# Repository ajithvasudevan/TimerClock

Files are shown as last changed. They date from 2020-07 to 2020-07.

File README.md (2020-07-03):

# TimerClock
An Arduino + RTC (and optionally Wemos) - based Clock and Timer with Alarm

# About
This project implements a Digital Alarm-Clock and Timer (time counter, also with alarm). 

# Button Operations
This Clock-Timer has 3 buttons - MODE, SET and RESET. All functions and settings are done using these buttons. This is described below.

## Displaying TIMER and CLOCK
When the ClockTimer is powered ON, it displays the CLOCK.
While CLOCK is displayed, long-pressing (LP) MODE button changes the display to TIMER, which displays counting time in minutes and seconds.
While TIMER is displayed, long-pressing (LP) MODE button changes the display to CLOCK, which displays the current time in 12-hr format.

## Timer and Resetting Timer to 00:00
The Timer counts time in seconds and minutes starting from 0 seconds, up to 99 minutes and 59 seconds, after which it starts counting from 0 seconds again.
During the time counting, the Timer alarm rings once when the displayed Time (mm:ss) matches the Timer Alarm setting.
While the Timer (or Clock) is displayed, the Timer count can be reset to 00:00 by short-pressing (SP) the RESET button. This causes the Timer to re-start counting from 0 seconds.

## Timer-Alarm Setting
While TIMER is displayed, MODE SP (Short Press) to change display to Timer-Alarm (Minutes and Seconds) with blinking Timer-Alarm Seconds. Now SET SP increments Timer-Alarm Seconds and SET LP decrements Timer Alarm Seconds.
MODE SP again blinks the Timer-Alarm Minutes display. Now SET SP increments Timer-Alarm Minutes and SET LP decrements Timer-Alarm Minutes.
MODE SP again returns the display to TIMER.

## Setting Timer Alarm to 00:00 quickly
The Timer-Alarm display can be set to 00:00 quickly by MODE LP during the blinking phase of Timer-Alarm Setting. This disables the Timer Alarm Ringing.

## Clock Setting
While CLOCK is displayed, MODE can be single-pressed (SP) to blink the Minutes display. Now SET SP increments Minutes and SET LP decrements Minutes.
MODE SP again blinks the Hours display. Now SET SP increments Hours and SET LP decrements Hours.
MODE SP again returns the display to CLOCK, with the changed time.

## Clock Alarm Setting
While CLOCK is displayed, SET LP to display the CLOCK ALARM TIME. Now MODE SP to blink the Clock Alarm Minutes display. Now SET SP increments Clock Alarm Minutes and SET LP decrements Clock Alarm Minutes.
MODE SP again blinks the Clock Alarm Hours display. Now SET SP increments Clock Alarm Hours and SET LP decrements Hours.
MODE MODE SP again returns the display to CLOCK ALARM TIME, with the changed Clock Alarm time.
MODE LP to exit Clock Alarm Setting and go back to Clock display.

# Schematic from KiCAD
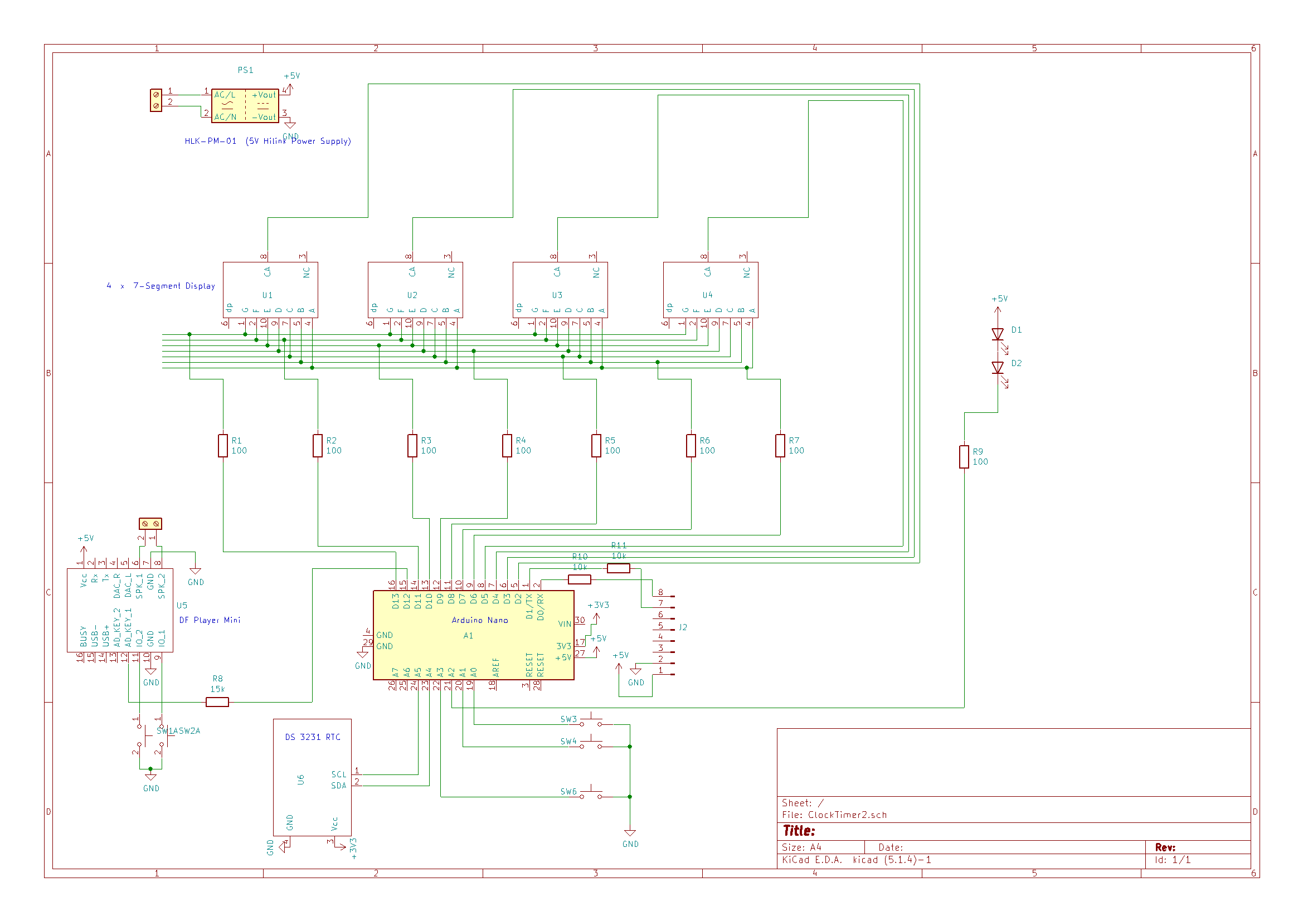
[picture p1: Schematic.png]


# PCM Image from KiCAD
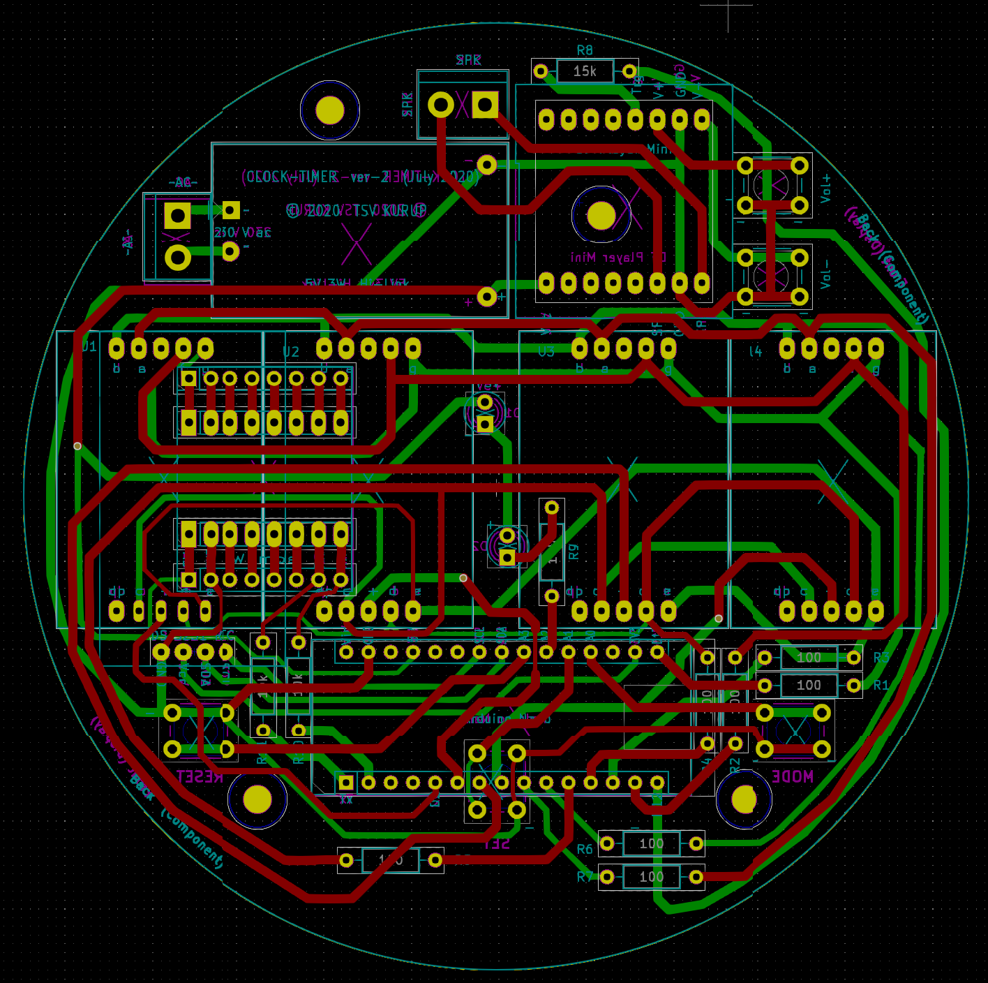
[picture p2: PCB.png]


# Notes

* A **DS3231 RTC** is used to keep accurate time. 
* The **DS 3231** may be removed and a **Wemos D1 Mini** with appropriate code may be used to push *Network Time* to the Arduino. This requires code changes to the Arduino as well. 
* The Wemos-Arduino interfacing is via Serial Rx-Tx lines.
* A6 and A7 of Arduino cannot be used as Digital IO pins. They can be used as Analog inputs only. So these are not suitable for use as button pins with libraries like AceButton.
* A DF Player Mini is used to make the alarm sound.
* Arduino's pin D13, being a communication pin as well, has digital noise on it during boot. Hence this is not suitable as a trigger pin for the DF Player Mini. Specifically, the DF Player starts playing continuously on boot if D13 is used.
* If the DF Player is triggered using Arduino pin D12 directly, there is a 'bep-bep-bep' kind of noise in the played back sound. This went away when a 15k resistor was used in this trigger line.

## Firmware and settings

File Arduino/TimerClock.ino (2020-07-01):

#include <Wire.h>
#include <EEPROM.h>
#include <AceButton.h>
#include "RTClib.h"
RTC_DS3231 rtc;
using namespace ace_button;

int modePin = A0;
int resetPin = A1;
int colonPin = A2;
int setPin = A3;
int alarmOut = 12;
int SET_BUTTON_STATE = 0;
int DISPLAY_MODE = 0;
int TIMER_MODE = 0;
int hr, mt;
int SET_DELAY = 50;
int timeChanged = 0;
int baseDelay = 1000;
int bias = 300;
int setDelayCtr = 0;

int CLOCK_SEC_PREV = 0;
int CLOCK_SEC = 0;
int CLOCK_MIN = 0;
int CLOCK_HR = 0;
int CLOCK_SEC_AL = 0;
int CLOCK_SEC_AL_ADDR = 0;

int CLOCK_MIN_AL_ADDR = 1;
int CLOCK_MIN_AL = EEPROM.read(CLOCK_MIN_AL_ADDR);

int CLOCK_HR_AL_ADDR = 2;
int CLOCK_HR_AL = EEPROM.read(CLOCK_HR_AL_ADDR);

int TIME_MIN = 0;
int TIME_SEC = 0;

int TIME_MIN_AL_ADDR = 3;
int TIME_MIN_AL = EEPROM.read(TIME_MIN_AL_ADDR);

int TIME_SEC_AL_ADDR = 4;
int TIME_SEC_AL = EEPROM.read(TIME_SEC_AL_ADDR);

int disp_left = 0;
int disp_right = 0;

int prev_second = 0;
int msec = 0;
long millisAtZero = 0;
bool zeroPad = true;
int colonState = 0;

AceButton mode_button(modePin, HIGH, 0);
AceButton set_button(setPin, HIGH, 1);
AceButton reset_button(resetPin, HIGH, 2);

void handleModeEvent(AceButton*, uint8_t, uint8_t);

// bits representing segments A through G (and decimal point) for numerals 0-9
const int numeral[10] = {
  //ABCDEFG
  B1111110, // 0
  B0110000, // 1
  B1101101, // 2
  B1111001, // 3
  B0110011, // 4
  B1011011, // 5
  B1011111, // 6
  B1110000, // 7
  B1111111, // 8
  B1111011, // 9
};
// pins for decimal point and each segment
// G,F,E,D,C,B,A
const int segmentPins[] = { 13, 11, 10, 9, 8, 7, 6 };
const int nbrDigits = 4; // the number of digits in the LED display
//dig 0 1 2 3
const int digitPins[nbrDigits] = { 2, 3, 4, 5 };


void handleEvent(AceButton* button, uint8_t eventType, uint8_t buttonState) {
  uint8_t id = button->getId();

  switch (eventType) {

    case AceButton::kEventClicked:

      if (id == mode_button.getId()) {
        DISPLAY_MODE++;
        if (DISPLAY_MODE > 2) DISPLAY_MODE = 0;
        
        if(DISPLAY_MODE == 1 || DISPLAY_MODE == 2) {
          if(TIMER_MODE == 0) {
            disp_left = CLOCK_HR;
            disp_right = CLOCK_MIN;
          }
        }
      }

      if (id == reset_button.getId()) {
        TIME_SEC = 0;
        TIME_MIN = 0;
//        digitalWrite(alarmOut, LOW);
//        delay(100);
//        digitalWrite(alarmOut, HIGH);        
      }
      
      if (id == set_button.getId()) {
        if(TIMER_MODE == 0) {
          if(DISPLAY_MODE == 1) { disp_right++; if(disp_right > 59) disp_right = 0; }
          if(DISPLAY_MODE == 2) { disp_left++; if(disp_left > 23) disp_left = 0; }
          rtc.adjust(DateTime(2025, 1, 1, disp_left, disp_right, 0));
          zeroPad = true;
        }
        if(TIMER_MODE == 1) {
          if(DISPLAY_MODE == 1) { TIME_SEC_AL++; if(TIME_SEC_AL > 59) TIME_SEC_AL = 0; }
          if(DISPLAY_MODE == 2) { TIME_MIN_AL++; if(TIME_MIN_AL > 99) TIME_MIN_AL = 0; }
          EEPROM.write(TIME_SEC_AL_ADDR, TIME_SEC_AL);
          EEPROM.write(TIME_MIN_AL_ADDR, TIME_MIN_AL);           
        }
        if(TIMER_MODE == 2) {
          if(DISPLAY_MODE == 1) { CLOCK_MIN_AL++; if(CLOCK_MIN_AL > 59) CLOCK_MIN_AL = 0; }
          if(DISPLAY_MODE == 2) { CLOCK_HR_AL++; if(CLOCK_HR_AL > 23) CLOCK_HR_AL = 0; }
          EEPROM.write(CLOCK_MIN_AL_ADDR, CLOCK_MIN_AL);
          EEPROM.write(CLOCK_HR_AL_ADDR, CLOCK_HR_AL);
        }                 
      }
      break;
    case AceButton::kEventLongPressed:
      if (id == mode_button.getId()) {
        if(DISPLAY_MODE == 0) {
          if(TIMER_MODE == 0) { TIMER_MODE = 1; }
          else if(TIMER_MODE == 1) { TIMER_MODE = 0; }
        }
        if(TIMER_MODE == 1 && (DISPLAY_MODE == 1 || DISPLAY_MODE == 2)) {
          TIME_SEC_AL = 0;
          TIME_MIN_AL = 0;
          EEPROM.write(TIME_SEC_AL_ADDR, TIME_SEC_AL);
          EEPROM.write(TIME_MIN_AL_ADDR, TIME_MIN_AL);           
        }        
        if(TIMER_MODE == 2) { TIMER_MODE = 0; DISPLAY_MODE = 0; }

      }
      if (id == set_button.getId()) {
        SET_BUTTON_STATE = 2;
        if((TIMER_MODE == 0) && DISPLAY_MODE == 0) { TIMER_MODE = 2; SET_BUTTON_STATE = 0; }
      }
      break;
    case AceButton::kEventReleased:
      if (id == set_button.getId()) {
        SET_BUTTON_STATE = 0;
      }
      break;
  }
}





void setup()
{
  //Serial.begin(115200);

  if (! rtc.begin()) {
//    Serial.println("Couldn't find RTC");
    while (1);
  }

  if (rtc.lostPower()) {
    //rtc.adjust(DateTime(F(__DATE__), F(__TIME__)));
    rtc.adjust(DateTime(2020, 6, 1, 0, 0, 0));
  }
  
   for(int i=0; i < 7; i++) {
      pinMode(segmentPins[i], OUTPUT); 
   }
   for(int i=0; i < nbrDigits; i++) {
      pinMode(digitPins[i], OUTPUT);
   }
   pinMode(colonPin, OUTPUT);
   pinMode(alarmOut, OUTPUT);
   digitalWrite(alarmOut, HIGH);
   pinMode(modePin, INPUT_PULLUP);
   pinMode(setPin, INPUT_PULLUP);
   pinMode(resetPin, INPUT_PULLUP);

  ButtonConfig* buttonConfig = ButtonConfig::getSystemButtonConfig();
  buttonConfig->setEventHandler(handleEvent);
  buttonConfig->setFeature(ButtonConfig::kFeatureClick);
  buttonConfig->setFeature(ButtonConfig::kFeatureLongPress);
} 


void calcClock() {
  DateTime now = rtc.now();
  CLOCK_SEC = now.second();
  CLOCK_MIN = now.minute();
  CLOCK_HR = now.hour();
  if(CLOCK_SEC != prev_second) { prev_second = CLOCK_SEC; millisAtZero = millis(); }
  msec = millis() - millisAtZero;
}

void calcTime() {
  if(CLOCK_SEC != CLOCK_SEC_PREV) { CLOCK_SEC_PREV = CLOCK_SEC; TIME_SEC++; if(TIME_SEC > 59) { TIME_SEC = 0; TIME_MIN++; if(TIME_MIN > 99) TIME_MIN = 0; }}
}

int C_ALM_FLG = 0;
int T_ALM_FLG = 0;
long c_alarm_start = 0;
long t_alarm_start = 0;

void checkClockAlarm() {
  if((millis() - c_alarm_start) > 5000) {
    if(CLOCK_SEC == 0 && CLOCK_MIN == CLOCK_MIN_AL && CLOCK_HR == CLOCK_HR_AL) {
      if(C_ALM_FLG == 0) {
        C_ALM_FLG = 1;
        c_alarm_start = millis();
        digitalWrite(alarmOut, LOW);
        delay(100);
        digitalWrite(alarmOut, HIGH);
      }
    }
  } else {
    C_ALM_FLG = 0;
  }
}


void checkTimerAlarm() {
  if(TIME_MIN_AL == 0 && TIME_SEC_AL == 0) return;
  
  if((millis() - t_alarm_start) > 5000) {
    if(TIME_MIN == TIME_MIN_AL && TIME_SEC == TIME_SEC_AL) {
      if(T_ALM_FLG == 0) {
        T_ALM_FLG = 1;
        t_alarm_start = millis();
        digitalWrite(alarmOut, LOW);
        delay(100);
        digitalWrite(alarmOut, HIGH);
      }
    }
  } else {
    T_ALM_FLG = 0;
  }
}

void colon() {
  if(colonState == 2) {
    if(msec < 500) digitalWrite(colonPin, LOW);
    else digitalWrite(colonPin, HIGH);
  } else if(colonState == 1) digitalWrite(colonPin, LOW);
  else digitalWrite(colonPin, HIGH);
}

void render() {
  int disp_num = 100 * disp_left + disp_right;
  showNumber(disp_num, zeroPad);
}


void showClockIfReqd() {
  if(DISPLAY_MODE == 0 && TIMER_MODE == 0) {
    disp_left = CLOCK_HR;

   if(disp_left > 12) disp_left = disp_left - 12;
   if(disp_left == 0) disp_left = 12;
    
    disp_right = CLOCK_MIN;
    zeroPad = false;
    colonState = 2;
  }
}


void showTimerIfReqd() {
  if(DISPLAY_MODE == 0 && TIMER_MODE == 1) {
    disp_left = TIME_MIN;
    disp_right = TIME_SEC;
    zeroPad = false;
    colonState = 1;
  }
}


void showTimerAlarmIfReqd() {
  if(DISPLAY_MODE != 0 && TIMER_MODE == 1) {
    disp_left = TIME_MIN_AL;
    disp_right = TIME_SEC_AL;
    zeroPad = true;
    colonState = 1;
  }
}


void showClockAlarmIfReqd() {
  if(TIMER_MODE == 2) {
    disp_left = CLOCK_HR_AL;
    disp_right = CLOCK_MIN_AL;
    zeroPad = true;
    colonState = 1;
  }
}


void checkSetButtonState() {
  if(setDelayCtr == 1) {
    if(SET_BUTTON_STATE == 2) {
      if(TIMER_MODE == 0) {
        if(DISPLAY_MODE == 1) { disp_right--; if(disp_right < 0 ) disp_right = 59; }
        if(DISPLAY_MODE == 2) { disp_left--; if(disp_left < 0) disp_left = 23; }
        rtc.adjust(DateTime(2025, 1, 1, disp_left, disp_right, 0));
        zeroPad = true;
      }
      if(TIMER_MODE == 1) {
        if(DISPLAY_MODE == 1) { TIME_SEC_AL--; if(TIME_SEC_AL < 0) TIME_SEC_AL = 59; }
        if(DISPLAY_MODE == 2) { TIME_MIN_AL--; if(TIME_MIN_AL < 0) TIME_MIN_AL = 99; }
        EEPROM.write(TIME_SEC_AL_ADDR, TIME_SEC_AL);
        EEPROM.write(TIME_MIN_AL_ADDR, TIME_MIN_AL);        
        
      }
      if(TIMER_MODE == 2) {
        if(DISPLAY_MODE == 1) { CLOCK_MIN_AL--; if(CLOCK_MIN_AL < 0) CLOCK_MIN_AL = 59; }
        if(DISPLAY_MODE == 2) { CLOCK_HR_AL--; if(CLOCK_HR_AL < 0) CLOCK_HR_AL = 23; }
        EEPROM.write(CLOCK_MIN_AL_ADDR, CLOCK_MIN_AL);
        EEPROM.write(CLOCK_HR_AL_ADDR, CLOCK_HR_AL);        
      }               
    }
  }
}



void loop()
{
    calcClock();
    checkClockAlarm();
    checkTimerAlarm();
    calcTime();
    colon();
    showClockIfReqd();
    showTimerIfReqd();
    checkSetButtonState();
    showTimerAlarmIfReqd();
    showClockAlarmIfReqd();
    render();
    setDelayCtr++; if(setDelayCtr == SET_DELAY) setDelayCtr = 0;
    mode_button.check();
    set_button.check();
    reset_button.check();
   
} 
 
void showNumber( int number, bool zeroPad)
{
    int orgNum = number;
    for( int digit = 0; digit <nbrDigits; digit++)  {
        if(zeroPad  || !((digit == 3 && orgNum < 1000) || (digit == 2 && orgNum < 100) || (digit == 1 && orgNum < 10))) showDigit( number % 10, digit);
        number = number / 10;
    }
} 
 
// Displays given number on a 7-segment display at the given digit position
void showDigit( int number, int digit) {
    digitalWrite( digitPins[digit], LOW );

   for(int segment = 0; segment < 7; segment++)  {
      boolean isBitSet = bitRead(numeral[number], segment);
      // isBitSet will be true if given bit is 1
      isBitSet = ! isBitSet; // Code Option*
      // uncomment the above Code Option line for common anode display
      digitalWrite( segmentPins[segment], isBitSet);
   }
   
   if(DISPLAY_MODE == 1 && ((digit == 0) || (digit == 1))) {  
      if(setDelayCtr < (SET_DELAY / 2)) digitalWrite( digitPins[digit], HIGH );
      else digitalWrite( digitPins[digit], LOW );
   } 
   else if(DISPLAY_MODE == 2 && ((digit == 2) || (digit == 3))) {  
      if(setDelayCtr < (SET_DELAY / 2)) digitalWrite( digitPins[digit], HIGH );
      else digitalWrite( digitPins[digit], LOW );
   } else digitalWrite( digitPins[digit], HIGH );
   
   
   
   if(number == 1) delayMicroseconds(baseDelay); 
   else if(number == 7)  delayMicroseconds(baseDelay + bias);
   else if(number == 4)  delayMicroseconds(baseDelay + 2*bias);
   else if(number == 3)  delayMicroseconds(baseDelay + 3*bias);
   else if(number == 2)  delayMicroseconds(baseDelay + 3*bias);
   else if(number == 5)  delayMicroseconds(baseDelay + 3*bias);
   else if(number == 6)  delayMicroseconds(baseDelay + 4*bias);
   else if(number == 9)  delayMicroseconds(baseDelay + 4*bias);
   else if(number == 0)  delayMicroseconds(baseDelay + 4*bias);
   else delayMicroseconds(baseDelay + 5*bias);
   digitalWrite( digitPins[digit], LOW );
}

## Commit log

2020-07-01 Initial version
    [ClockTimer2-B_Cu.gbl, ClockTimer2-B_Mask.gbs, ClockTimer2-B_Paste.gbp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]
2020-07-01 Added Arduino code
